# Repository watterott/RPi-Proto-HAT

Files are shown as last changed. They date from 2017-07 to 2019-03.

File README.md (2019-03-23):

# RPi-Proto-HAT
Prototyping Area HAT (Hardware Attached on Top) for Raspberry Pi.

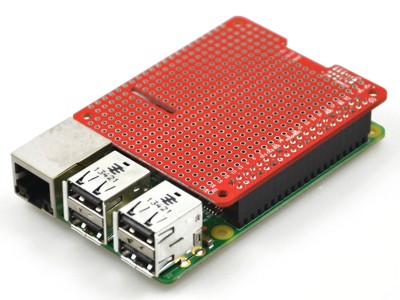
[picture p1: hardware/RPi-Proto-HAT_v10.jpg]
RPi-Proto-HAT (http://www.watterott.com/en/RPi-Proto-HAT)


* Prototyping Area
* ID EEPROM
* [Raspberry Pi HAT](https://github.com/raspberrypi/hats) compatible (40 pin connector)
* Open-Source and released under the [Creative Commons Attribution Share-Alike License](https://creativecommons.org/licenses/by-sa/4.0/).
* **[Documentation on learn.watterott.com](https://learn.watterott.com)**

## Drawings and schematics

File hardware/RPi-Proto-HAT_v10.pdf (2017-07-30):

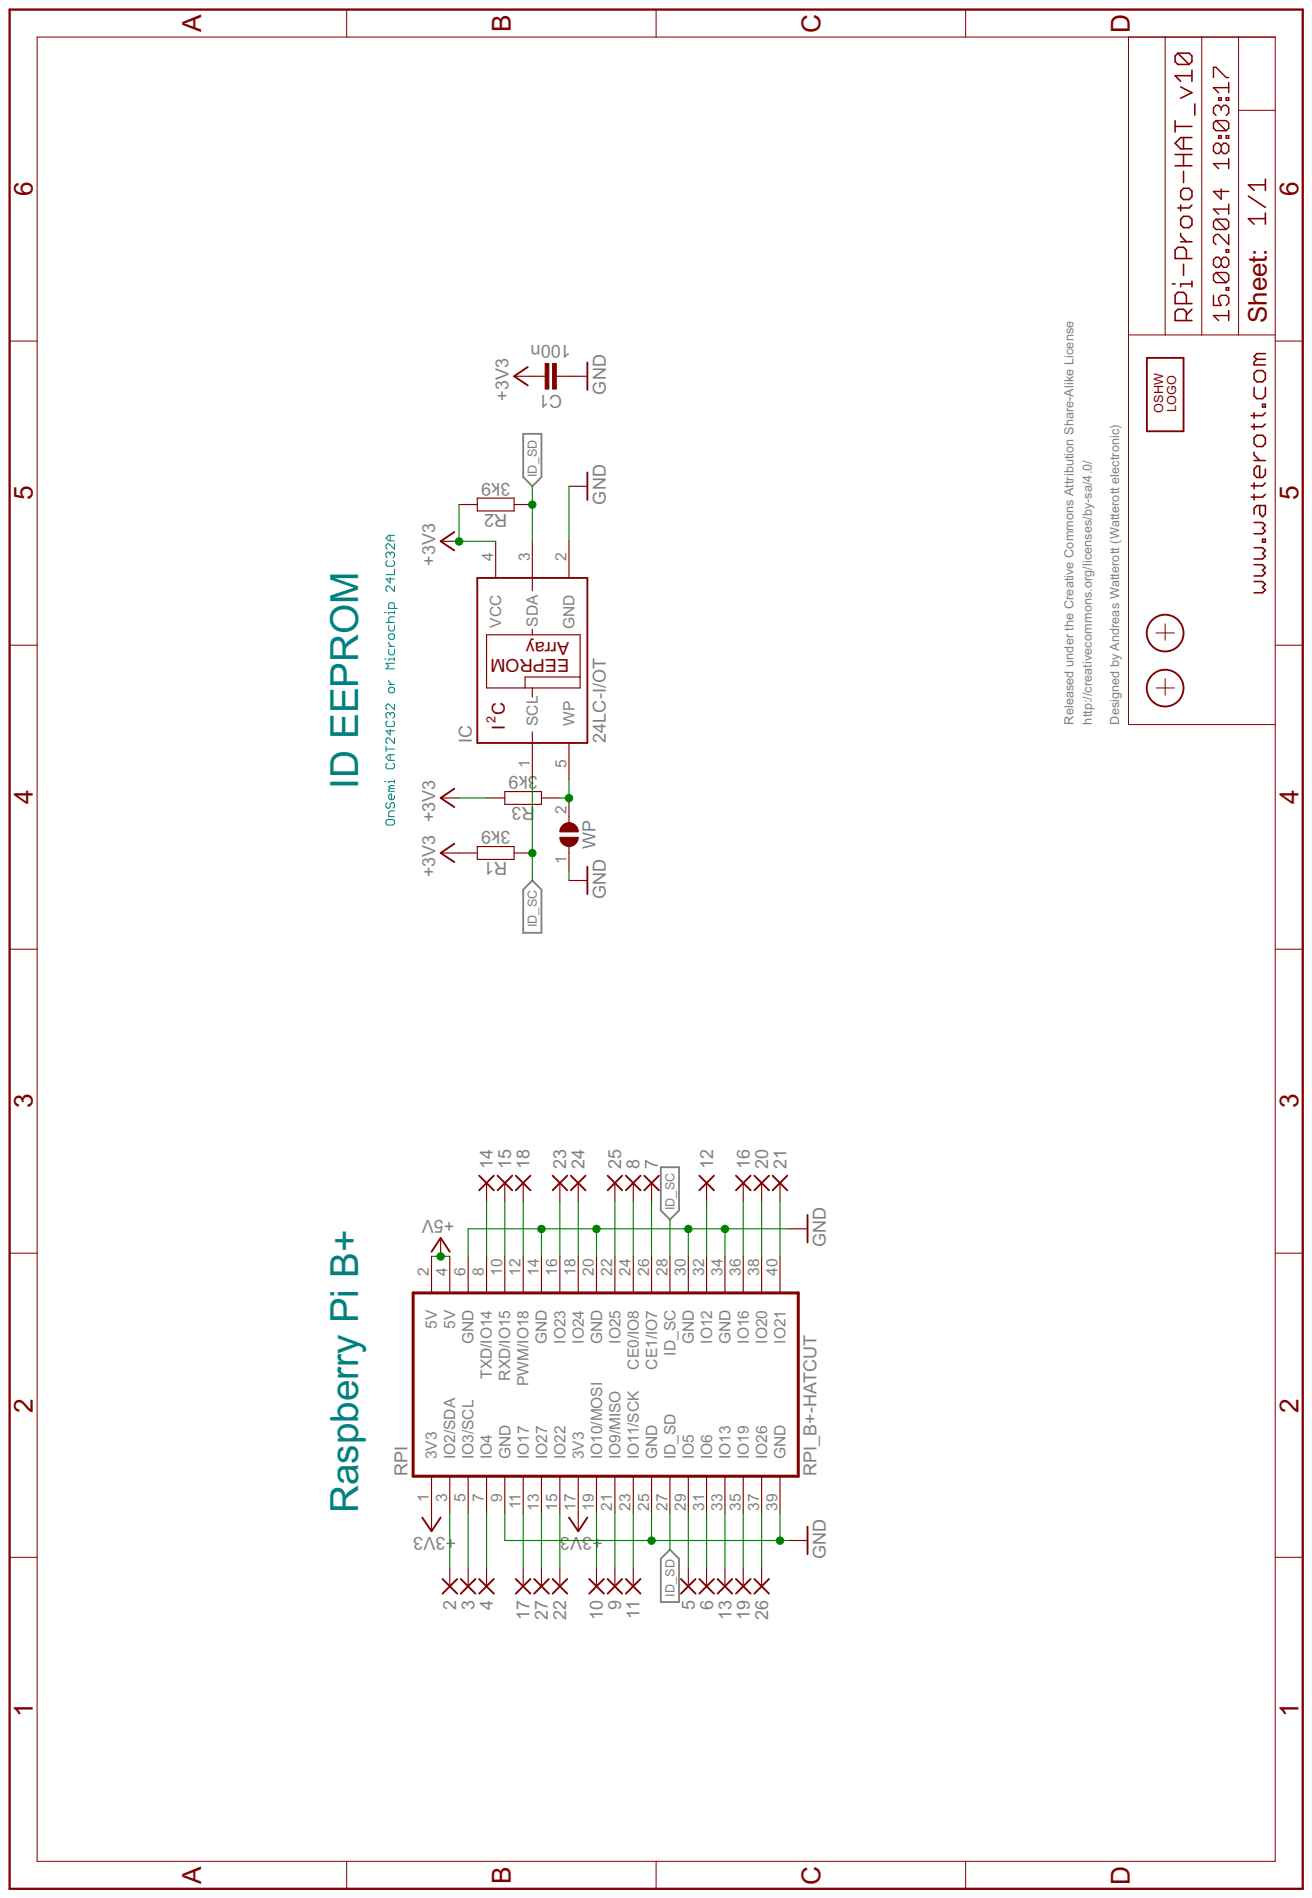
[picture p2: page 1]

V5+ GND GND GND +3V3 +3V3 +3V3 GND RPI_B+-HATCUT 3V3+ 3V3+ n001 +3V3 GND 9k3 9k39k3 24LC-I/OT Released under the Creative Commons Attribution Share-Alike License http://creativecommons.org/licenses/by-sa/4.0/ Designed by Andreas Watterott (Watterott electronic) 2 1 WP RPI 3V3 1 IO2/SDA 3 IO3/SCL 5 5V 2 5V 4 GND 6 IO4 7 GND 9 TXD/IO14 8 RXD/IO15 10 IO17 11 IO27 13 IO22 15 PWM/IO18 12 GND 14 IO23 16 3V3 17 IO10/MOSI 19 IO24 18 GND 20 IO9/MISO 21 IO11/SCK 23 GND 25 IO25 22 CE0/IO8 24 CE1/IO7 26 ID_SD 27 IO5 29 IO6 31 IO13 33 IO19 35 IO26 37 GND 39 ID_SC 28 GND 30 IO12 32 GND 34 IO16 36 IO20 38 IO21 40 1C 1R2R3R VCC 4 GND 2 WP 5 SCL 1 SDA 3 IC 2341727221091156261913 2120161228752423181514 ID_SD ID_SD ID_SC ID_SC Sheet: ABCD 1 2 3 4 5 6 ABCD 1 2 3 4 5 6 OSHW LOGO yarr A MORPEE I C2 Raspberry Pi B+ ID EEPROM

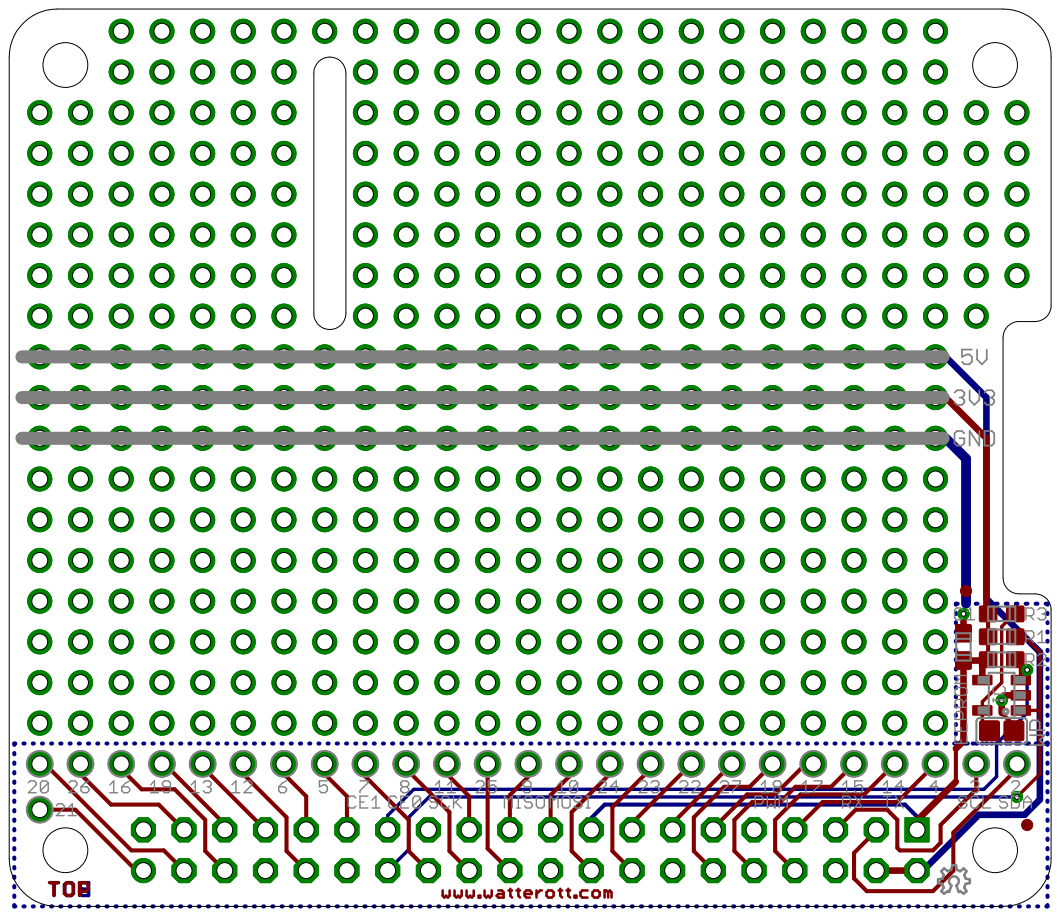
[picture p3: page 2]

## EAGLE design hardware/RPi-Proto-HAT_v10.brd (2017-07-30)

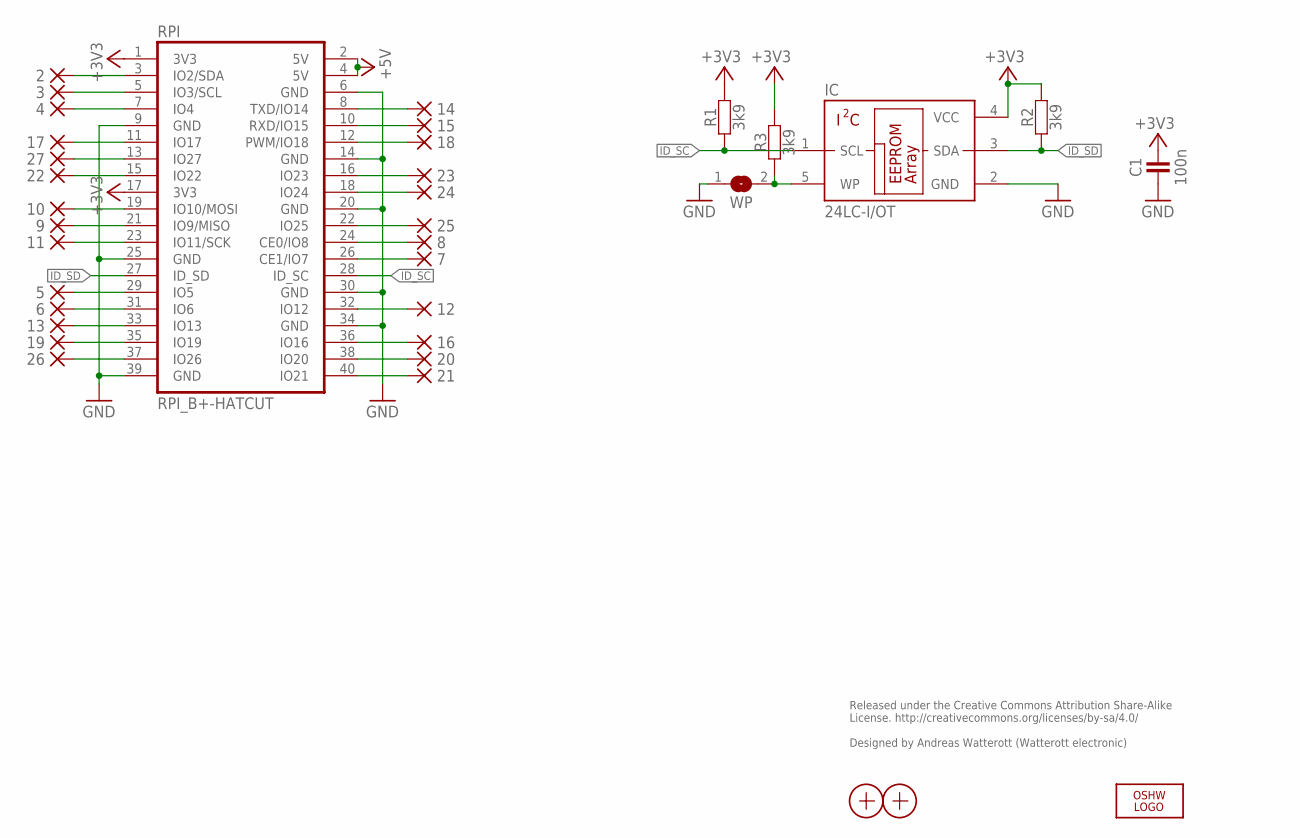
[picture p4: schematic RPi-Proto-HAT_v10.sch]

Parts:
2, 3, 4, 5, 6, 7, 8, 9, 10, 11, 12, 13, 14, 15, 16, 17, 18, 19, 20, 21, 22, 23, 24, 25, 26, 27: PAD-1-1.6
C1: 100n; R0603
IC: 24LC-I/OT; SOT23-5
LOGO2: OSHW_LOGOX0070; OSHW_6X70
R1, R2, R3: 3k9; R0603
RPI: RPI_B+-HATCUT; RPI-B+HAT_CUTOUT
WP: JUMPER2-NOCREAM; JUMPER2_NC
X1, X2: PASSER-07; PASSER_07MM

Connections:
+3V3: C1.2, IC.4 (VCC), R1.2, R2.2, R3.2, RPI.1 (3V3), RPI.17 (3V3)
+5V: RPI.2 (5V), RPI.4 (5V)
GND: C1.1, IC.2 (GND), RPI.6 (GND), RPI.9 (GND), RPI.14 (GND), RPI.20 (GND), RPI.25 (GND), RPI.30 (GND), RPI.34 (GND), RPI.39 (GND), WP.1
ID_SC: IC.1 (SCL), R1.1, RPI.28 (ID_SC)
ID_SD: IC.3 (SDA), R2.1, RPI.27 (ID_SD)
IO2: 2.1, RPI.3 (IO2/SDA)
IO3: 3.1, RPI.5 (IO3/SCL)
IO4: 4.1, RPI.7 (IO4)
IO5: 5.1, RPI.29 (IO5)
IO6: 6.1, RPI.31 (IO6)
IO7: 7.1, RPI.26 (CE1/IO7)
IO8: 8.1, RPI.24 (CE0/IO8)
IO9: 9.1, RPI.21 (IO9/MISO)
IO10: 10.1, RPI.19 (IO10/MOSI)
IO11: 11.1, RPI.23 (IO11/SCK)
IO12: 12.1, RPI.32 (IO12)
IO13: 13.1, RPI.33 (IO13)
IO14: 14.1, RPI.8 (TXD/IO14)
IO15: 15.1, RPI.10 (RXD/IO15)
IO16: 16.1, RPI.36 (IO16)
IO17: 17.1, RPI.11 (IO17)
IO18: 18.1, RPI.12 (PWM/IO18)
IO19: 19.1, RPI.35 (IO19)
IO20: 20.1, RPI.38 (IO20)
IO21: 21.1, RPI.40 (IO21)
IO22: 22.1, RPI.15 (IO22)
IO23: 23.1, RPI.16 (IO23)
IO24: 24.1, RPI.18 (IO24)
IO25: 25.1, RPI.22 (IO25)
IO26: 26.1, RPI.37 (IO26)
IO27: 27.1, RPI.13 (IO27)
WP: IC.5 (WP), R3.1, WP.2

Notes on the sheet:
Released under the Creative Commons Attribution Share-Alike License. http://creativecommons.org/licenses/by-sa/4.0/ Designed by Andreas Watterott (Watterott electronic)

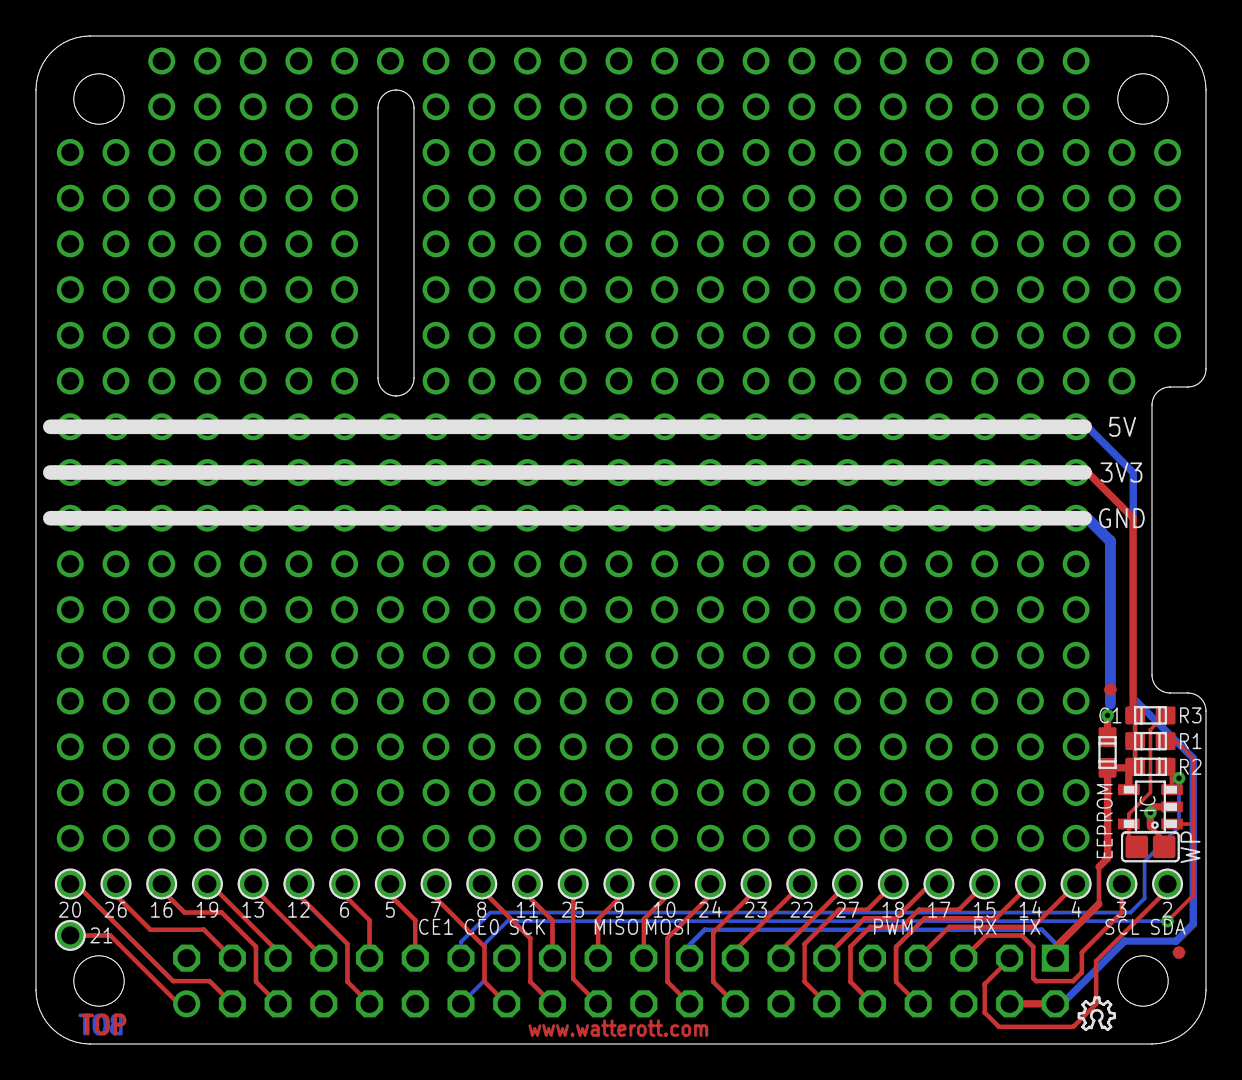
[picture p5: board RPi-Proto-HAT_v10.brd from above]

Board: 2 copper layers, 65.0 x 56.0 mm, 36 parts (0 on the bottom side), 32 nets.
